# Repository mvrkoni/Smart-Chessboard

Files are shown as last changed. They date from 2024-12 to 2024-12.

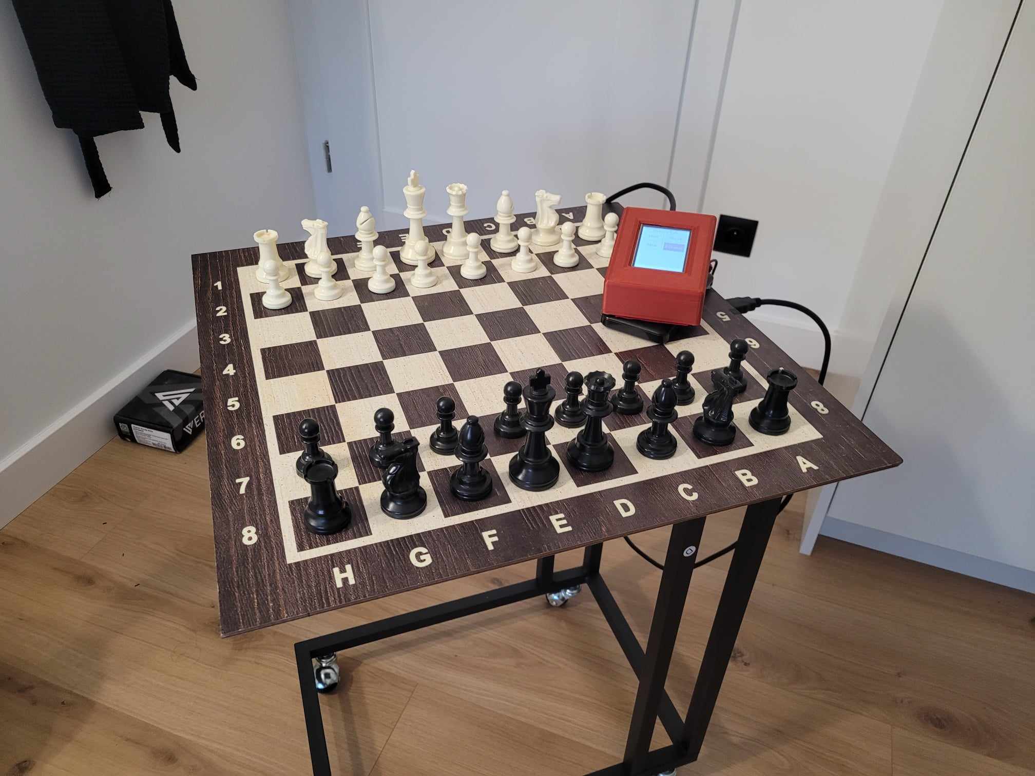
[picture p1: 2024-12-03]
Results_Images/465933476_549978397827990_7550162248625095663_n.jpg

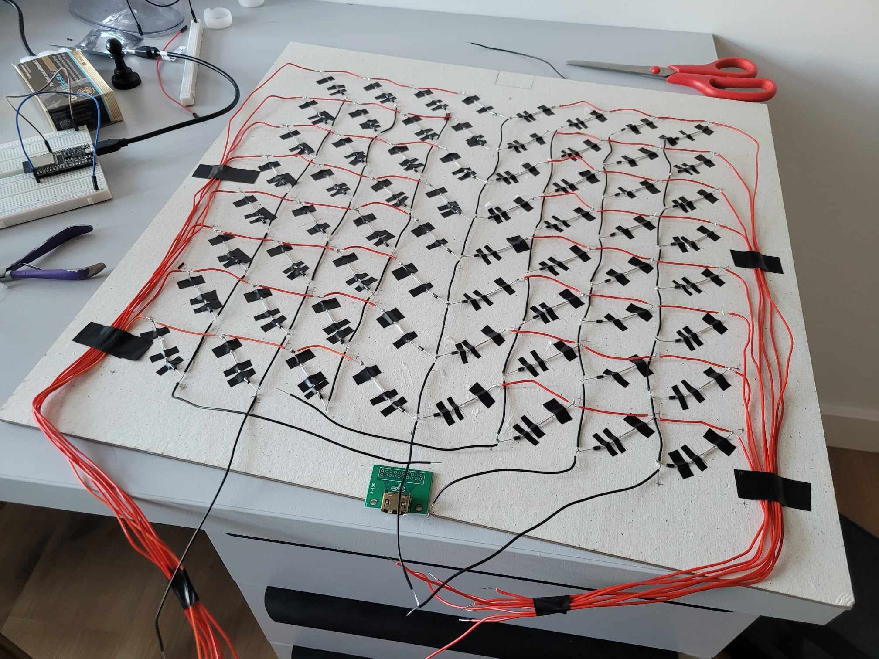
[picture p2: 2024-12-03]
Results_Images/464932877_1571432690404527_1509091106561519744_n.jpg

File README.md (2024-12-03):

                          SmartChessboard

This project is an ESP32-powered chessboard inspired by https://github.com/omercier01/Chessboard repository. It tracks chess pieces and sends game data to an external service like Lichess.

1. Documentation
   All details including:
   - Schematics: Electrical diagrams.
   - Code Explanation: Full code breakdown.
   - Setup Instructions: How to assemble and upload the code.

Everything is available in the documentation folder.

2. Result Images
   See the board in action in the Results_images folder.

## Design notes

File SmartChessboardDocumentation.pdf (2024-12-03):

Politechnika Lubelska
Wydział Elektrotechniki i Informatyki Inżynierskie Zastosowania Informatyki w Elektrotechnice

Imię i nazwisko autora:
Marek Rowiński
nr 93342

# Szachownica elektroniczna SmartBoard

Promotor:
dr inż. Jacek Majcher

Lublin, 2024

### Spis treści:

### 5. Projekt hardware’u

### 6. Projekt software’u

### 7. Analiza i wnioski

7.3. Możliwe usprawnienia i przyszłe kierunki rozwoju projektu.......17

### 1. Wprowadzenie

Elektroniczne szachownice to nowoczesne narzędzia, które rewolucjonizują tradycyjną grę w szachy poprzez integrację zaawansowanych technologii. Moim
celem jest | stworzenie | innowacyjnej | elektronicznej | szachownicy, | która
automatycznie rozpoznaje ruchy, umożliwia grę online i ułatwi analizę i█archiwizację partii.

Motywacją do realizacji projektu jest rosnące zainteresowanie grą w szachy oraz potrzeba dostarczenia narzędzia, które umożliwi graczom śledzenie rozgrywek w sposób nowoczesny i efektywny. Dzięki elektronicznym szachownicom, gra staje się bardziej dostępna, interaktywna i inspirująca.

### 2. Wymagania systemowe

System ma realizować szereg funkcji, które mają na celu ułatwienie i█udoskonalenie doświadczenia użytkownika. Główne funkcje obejmują:

- Gra online na platformie Lichess: Użytkownik będzie mógł grać partie szachów online poprzez integrację z platformą Lichess. System umożliwi logowanie się na konto Lichess, wyszukiwanie przeciwników oraz rozgrywanie partii w czasie rzeczywistym.
- Archiwizowanie partii na koncie Lichess: Podczas rozgrywki system będzie automatycznie zapisywał przebieg partii w formacie UCI na platformie Lichess, umożliwiając użytkownikowi późniejszą analizę i archiwizację rozgrywki.
- Interaktywny interfejs użytkownika: System będzie posiadał intuicyjny interfejs użytkownika, który umożliwi łatwe korzystanie z funkcji, takich jak rozpoczęcie nowej gry, wybór przeciwnika online oraz dostęp do zapisanych partii.

Dodatkowo, celem projektu jest stworzenie elektronicznej szachownicy łączącej funkcjonalność, estetykę i ergonomię, umożliwiającej grę w szachy w sposób wygodny i nowoczesny. Szachownica automatycznie rejestruje ruchy podczas gry, przesyła je do platformy Lichess, gdzie są zapisywane w formacie UCI, co eliminuje konieczność ręcznego wprowadzania posunięć. Dzięki temu użytkownik może analizować partie, korzystać z programów szachowych lub grać online – zarówno przeciwko komputerowi, jak i innym graczom na Lichess. Szachownica działa także jako urządzenie wejściowe, przenosząc ruchy wykonane na planszy bezpośrednio do aplikacji lub stron internetowych.

### 3. Sposób użytkowania

Elektroniczna szachownica jest wyposażona w wyświetlacz z interfejsem, który pokazuje czas trwania partii oraz oferuje podstawowe funkcje, takie jak gra online lub z komputerem (Stockfish 5). Aby rozpocząć grę, należy poprawnie ułożyć figury na szachownicy zgodnie z zasadami szachowymi. Aby sprawdzić czy położenie figur pokrywa się z czujnikami należy wejść do debug mode klikając boczny przycisk i wybrać odpowiednią opcję (Testowanie kontraktonów). Po ustawieniu figur, użytkownik może wybrać odpowiednią opcję na ekranie dotykowym, aby zagrać online lub z silnikiem.

Podczas gry, po wykonaniu ruchu przez gracza, należy delikatnie nacisnąć odpowiedni przycisk na ekranie dotykowym, aby wysłać ruch do serwerów Lichess. Wszystkie partie są zapisywane i dostępne na stronie lichess.org na koncie marekr93342. Ważne jest, aby figury były umieszczane równo i dokładnie na polach szachownicy, co zapewni prawidłowe działanie systemu detekcji ruchu.

W celu zapewnienia optymalnej wydajności i dokładności, należy dbać o█regularne czyszczenie powierzchni szachownicy i wyświetlacza.

### 4. Środki ostrożności zestawu elektronicznego

Do wykrywania elektronicznych figur szachowych na szachownicy używany jest rezonans elektromagnetyczny. Silny sygnał wygenerowany przez różnego rodzaju nadajniki w pobliżu urządzenia może spowodować samoistne i wadliwe wykrycie nieistniejących figur na danych polach szachownicy, tzw. zjawisko "figur duchów".

Jeśli problemy z wykrywaniem "figur duchów" występują podczas używania systemu, przyczyną może być umieszczenie szachownicy zbyt blisko ekranów plazmowych, monitorów LCD, głośników, zasilaczy i innych podobnych urządzeń. Metalowe powierzchnie lub przedmioty umieszczone obok, pod szachownicą lub pod stołem, na którym się ona znajduje, mogą zmniejszyć czułość systemu, co może spowodować błędy w wykrywaniu figur.

Nie należy umieszczać szachownicy na metalowej tablicy lub stole z█metalową konstrukcją pod blatem.

Sprzęt należy chronić przed skrajnymi warunkami atmosferycznymi, takimi jak deszcz, wysoka temperatura czy intensywne nasłonecznienie.

### 5. Projekt hardware’u

### 5.1. Schematy elektryczne:

Schematy | elektryczne | przedstawiają | szczegółowy | układ | połączeń
i█komponentów zastosowanych w elektronicznej szachownicy. Obejmują one rozmieszczenie czujników detekcji ruchu, układ zasilania, moduły komunikacyjne oraz interfejsy do przesyłania danych.

Schemat (Sch. 1.) składa się z diody Schottky'ego oraz kontraktonu. Kontraktony są używane do wykrywania obecności figur z wbudowanymi magnesami, natomiast dioda zapobiega powstawaniu fałszywych sygnałów w█układzie. Na schemacie (Sch. 2.) przedstawiono problem fałszywego odczytu sygnału w przypadku braku diod. Jeśli na trzech polach (A, C, D) są figury (zamknięte przełączniki), a na jednym polu (B) jej nie ma (otwarty przełącznik), sygnał mógłby niechcący przejść przez inne zamknięte pola i dać błędny odczyt.

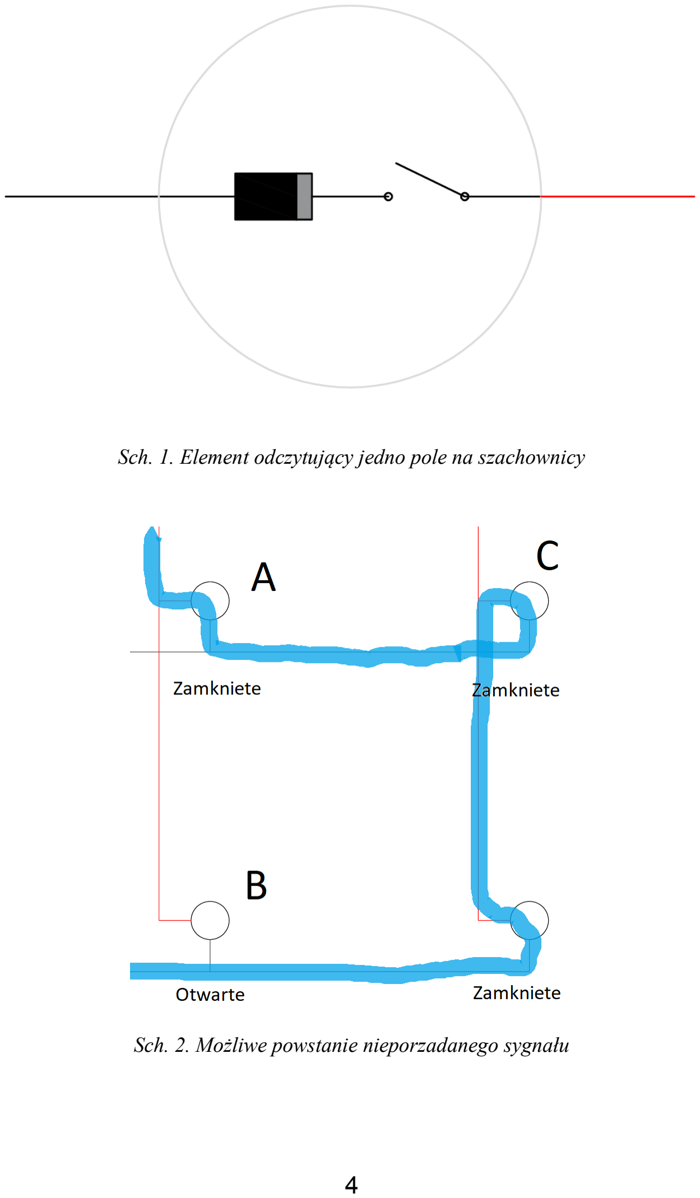
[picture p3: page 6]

Sch. 1. Element odczytujący jedno pole na szachownicy

Sch. 2. Możliwe powstanie nieporzadanego sygnału

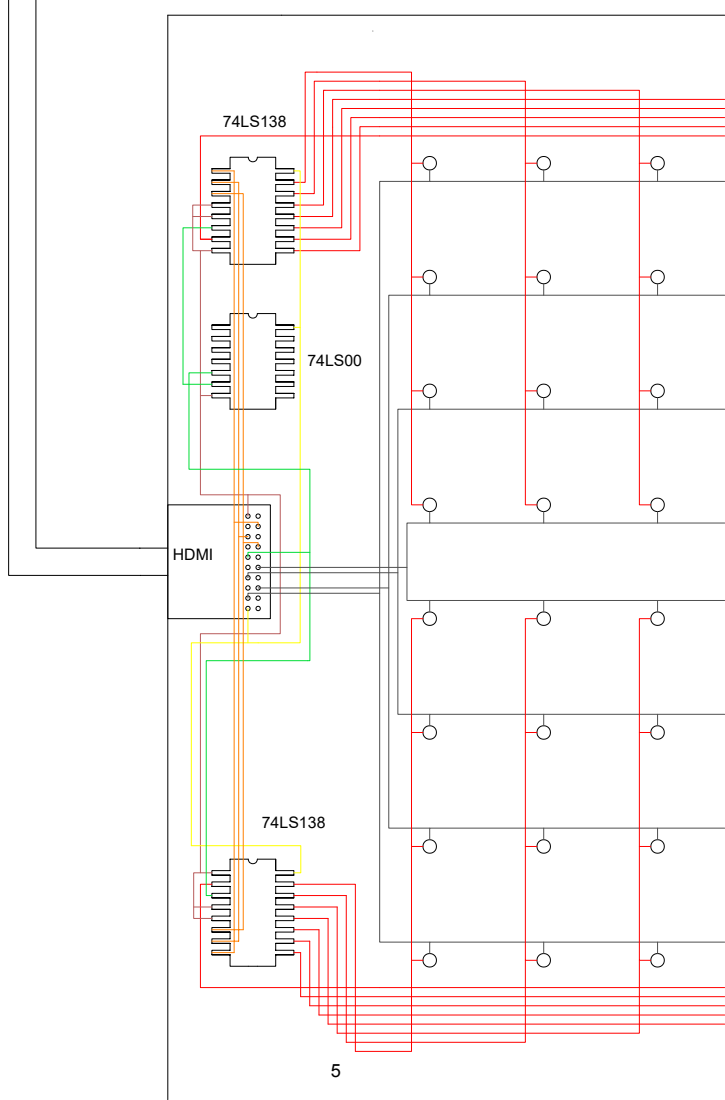
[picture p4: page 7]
HDMI

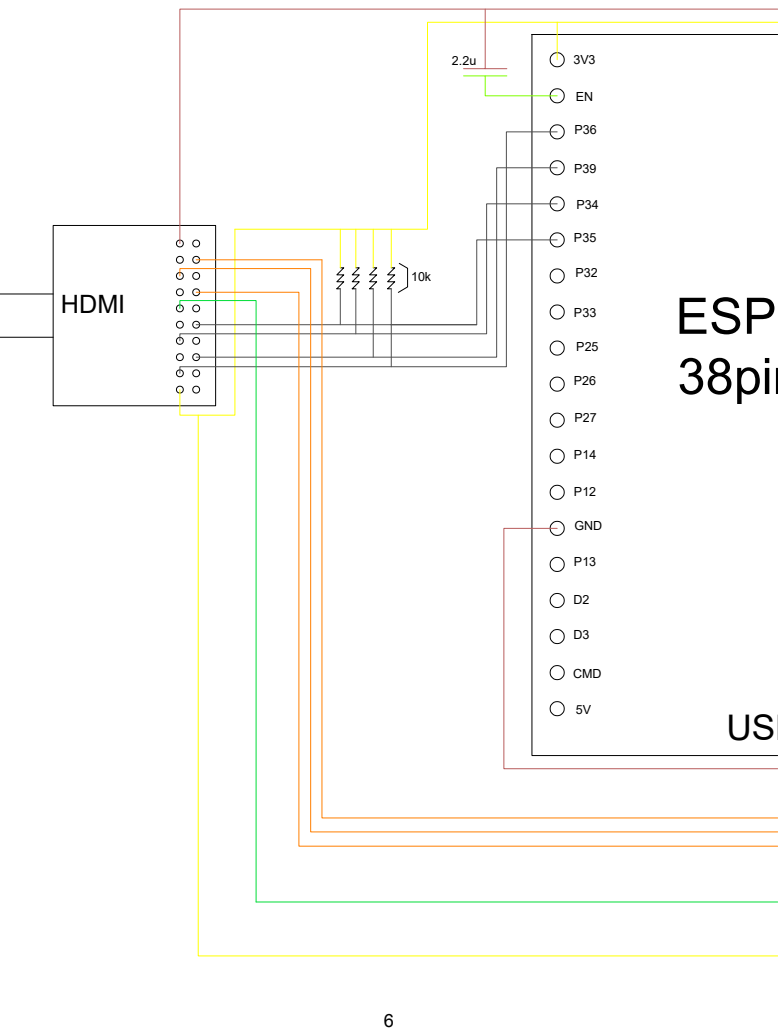
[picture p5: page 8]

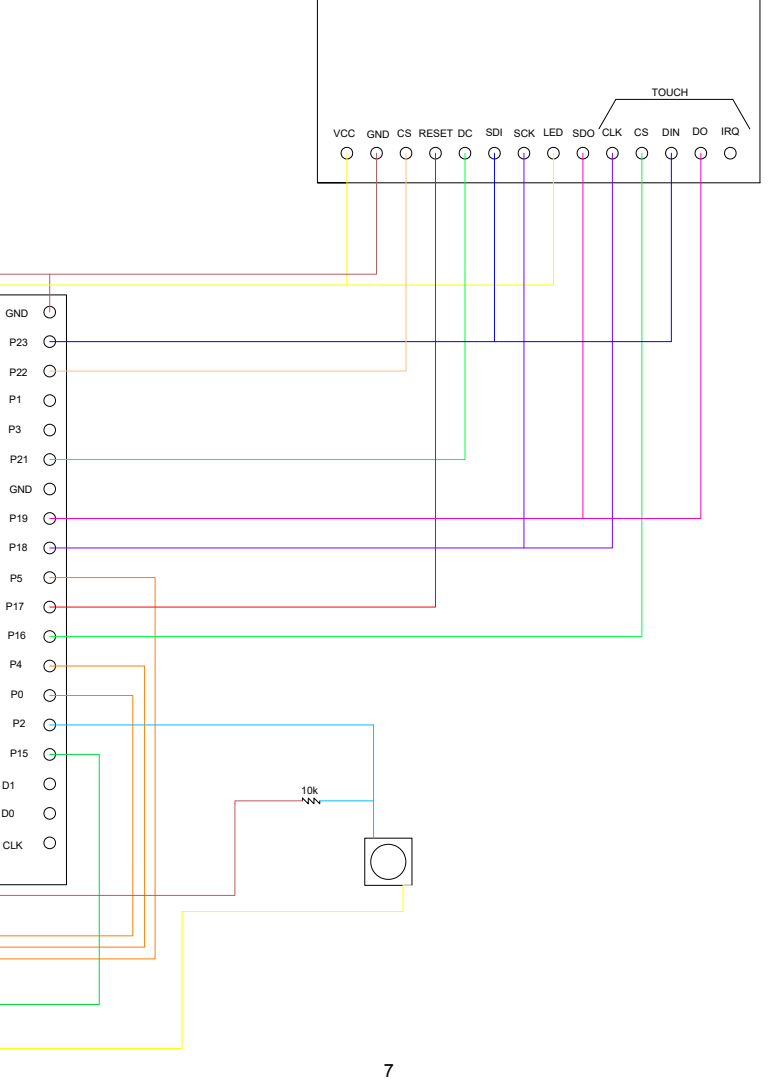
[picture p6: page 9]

VCC GND CS RESET DC SDI SCK LED SDO CLK CS DIN DO IRQ

W analizie schematów elektronicznych szachownicy można wyróżnić kluczowe elementy:

1. Rezystory 10k
Rezystory pełnią funkcję pull-up lub pull-down, stabilizując stan logiczny sygnału w przypadku jego braku, lub ograniczać prąd, chroniąc układ przed uszkodzeniem w razie zwarcia.
2. Kondensator 2,2 µF do masy (GND)
Kondensator eliminuje zakłócenia i stabilizuje napięcie, co zapobiega problemom podczas ładowania kodu.

### 5.2. Lista oraz opis poszczególnych komponentów:

− ESP32-DevKitC-32E V4 WiFi + BT 4.2

Platforma mikroprocesorowa wyposażona w moduł ESP-WROOM-32E. Oferuje wbudowane WiFi i Bluetooth 4.2, co umożliwia bezprzewodową komunikację z█siecią i innymi urządzeniami.

− Wyświetlacz dotykowy TFT LCD 2,8″ 240x320px

Wyświetlacz dotykowy o przekątnej 2,8 cala i rozdzielczości 240x320 pikseli. Służy do interaktywnej obsługi urządzenia, wyświetlania czasu gry, opcji menu oraz innych istotnych informacji. Technologia TFT zapewnia wyraźny obraz i█dobre kąty widzenia.

− Kabel HDMI - HDMI NEDIS 1.5 m

Standardowy kabel HDMI używany jako zbiór kabli do przesyłu i odbioru sygnałów z szachownicy.

− Demultiplexer 3 na 8 linii 74LS138

Układ scalony, który pozwala na wybór jednego z ośmiu wyjść na podstawie trzech sygnałów wejściowych. Umożliwia efektywne sterowanie wieloma liniami sygnałowymi przy użyciu mniejszej liczby przewodów sterujących.

− Bramka NAND 74LS00

Służy do negacji sygnału (zielony kabel). Sygnał zerojedynkowy dodany do zestawu sterującego (pomarańczowe kable) sprawia, że program rozróznia strony szachownicy

− Szachownica i figury szachowe

Fizyczna szachownica i figury służące jako sensor. Figury wyposażone są w magnesy neodymowe, które współpracują z kontaktronami umieszczonymi pod szachownicą, pozwalając na precyzyjne wykrywanie ruchów.

− Dioda Schottky’ego

Dioda półprzewodnikowa charakteryzująca się niskim napięciem przewodzenia i█dużą szybkością działania. W układzie zapobiega przepływowi sygnału w niepożądanym kierunku, eliminując błędy odczytu podczas wykrywania pozycji figur.

− Konstrukcja przewodowa z wyłącznikiem układu

Służy do zasilania oraz przesyłania danych między urządzeniami. Może być używany do podłączenia modułu ESP32 do komputera w celu programowania lub zasilania.

− Zestyk kontaktron prosty 14mm

Proste zestyki kontaktronowe, które zamykają obwód w obecności pola magnetycznego. Umieszczone pod polami szachownicy, umożliwiają wykrywanie pozycji figur szachowych wyposażonych w magnesy.

− Rezystor justPi THT CF węglowy 1/4W 10kΩ

Rezystory węglowe, używane do ograniczania prądu w obwodach. Chronią inne komponenty przed uszkodzeniem przez nadmierny prąd oraz służą do ustawiania odpowiednich poziomów sygnałów.

− Magnes neodymowy okrągły 6x3mm

Magnesy neodymowe, które są umieszczane w figurach szachowych. Oddziałują na zestyki kontaktronowe pod szachownicą, umożliwiając precyzyjne wykrywanie pozycji figur.

− Powerbank Tracer 10000mAh

Powerbank służący jako źródło zasilania.

Dodatkowo:

− Przewody połączeniowe
− Obudowa wydrukowana w drukarce 3D
− Porty HDMI
− Adapter USB Typ C - Micro USB LANBERG AD-UC-UM-01 − Tact switch 6x6

### 5.3. Kosztorys

Nazwa: | Cena (w zł): | Ilość:
ESP32 - 38pin | 59,99 | 1x
Wyświetlacz | 40,00 | 1x
74LS138n | 1,50 | 3x
74LS00n | 6,00 | 1x
Zestaw figur | 33,00 | 1x
Szachownica | 59,00 | 1x
Diody | 0,15 | 64x
Magnesy | 0,55 | 34x
Kontraktony | 0,85 | 64x
Wyłącznik układu | 16,24 | 1x
Zestaw kabli | 59,90 | 1x
Adapter do ESP32 | 16,00 | 1x
Adapter USB - B | 6,99 | 1x
Obudowa | 30,00 | 1x
Śrubki i nakładki | 3,00 | 1x
Powerbank | 50,00 | 1x
Płytka stykowa 170o. | 3,50 | 2x
Porty HDMI | 5,55 | 2x
SUMA: | 501,12

### 6. Projekt software'u

W systemie działa kilka kluczowych mechanizmów, które pozwalają na rozgrywanie partii, śledzenie ruchów, obsługę różnych stanów gry oraz interakcję z użytkownikiem poprzez menu. Poniżej znajduje się bardziej szczegółowy opis poszczególnych elementów i ich logiki:

### 6.1. Odczytywanie figur z szachownicy

Szachownica jest wyposażona w kontraktony, które umożliwiają wykrywanie obecności figur na poszczególnych polach. Odczytywanie figur odbywa się poprzez skanowanie stanu szachownicy i porównywanie go z█oczekiwanym stanem (Rys. 1-3.):

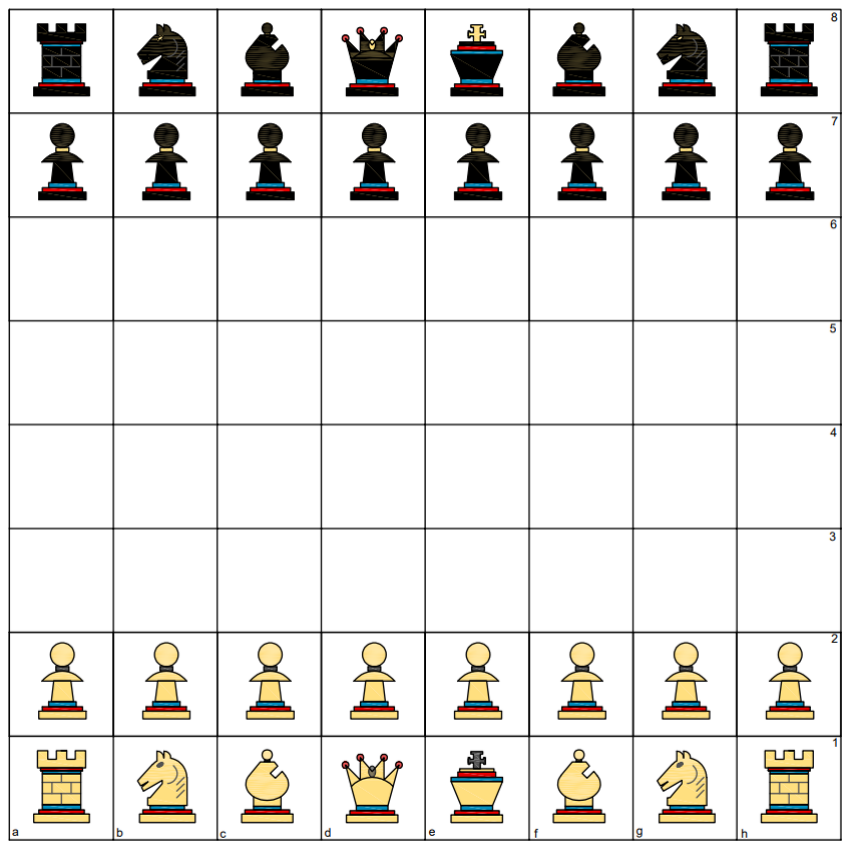
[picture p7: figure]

Sch. 5. Pierwotne ustawienie figur

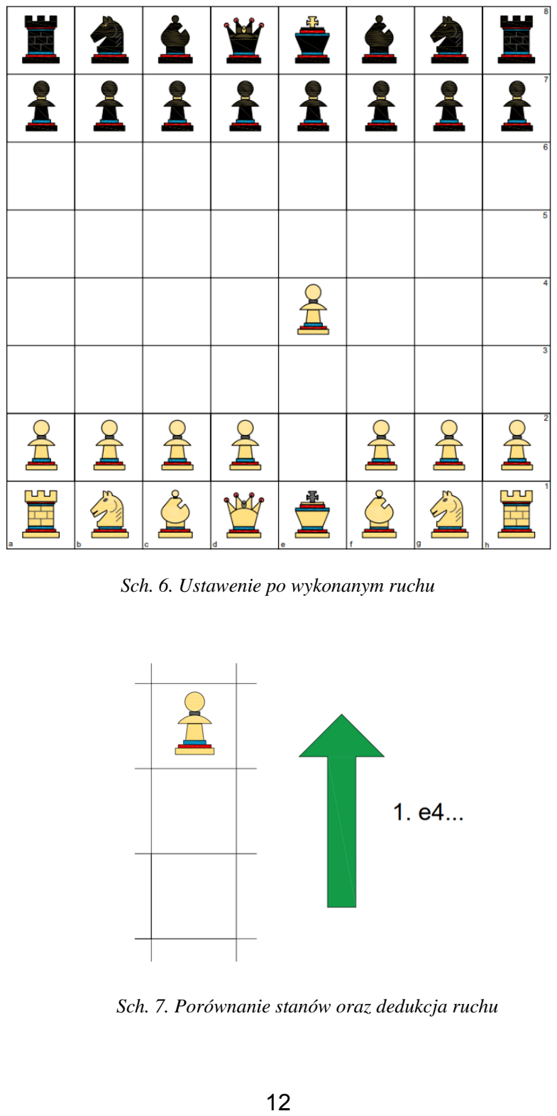
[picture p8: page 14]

Sch. 6. Ustawenie po wykonanym ruchu

Sch. 7. Porównanie stanów oraz dedukcja ruchu

Kluczowe funkcje związane z tym procesem to:

- checkUpdatedSquaresForMoves(): Ta funkcja sprawdza, które pola na szachownicy zostały zmienione od ostatniego odczytu. Na tej podstawie określa, jakie ruchy zostały wykonane. W zależności od liczby zmienionych pól rozpoznaje różne rodzaje ruchów (prosty ruch, bicie, promocja, en passant, roszada).
- getChangedSquares(): Funkcja ta zwraca listę pól, które zostały zmienione od ostatniego skanu. Jest to kluczowa funkcja do śledzenia zmian na szachownicy.
- isPlayerPiece() i isOpponentPiece(): Te funkcje sprawdzają, czy dana figura na określonym polu należy do gracza, czy do przeciwnika.

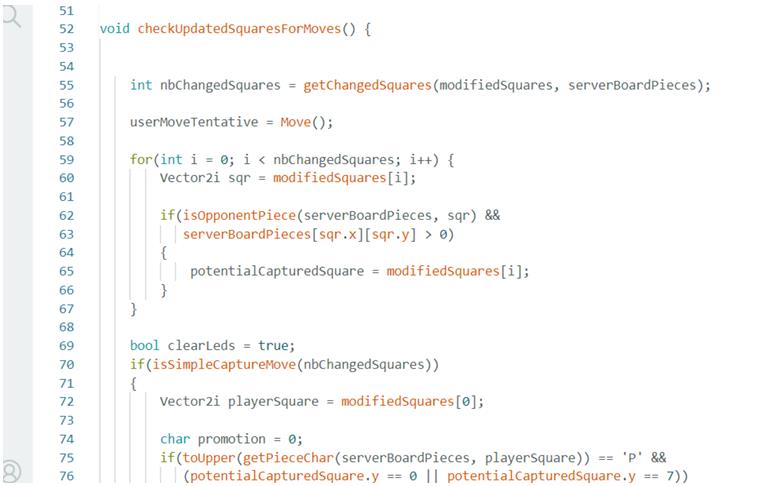
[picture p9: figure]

Zdj. 1. Element kodu

### 6.2. Tworzenie ruchów w formacie UCI

UCI (Universal Chess Interface) to standardowy protokół komunikacyjny dla silników szachowych. System generuje ruchy w formacie UCI na podstawie wykrytych ruchów. Oto kluczowe elementy tego procesu:

- squaresToMove(): Ta funkcja tworzy obiekt ruchu (ang. Move) na podstawie pozycji początkowej i końcowej figury oraz ewentualnej promocji. Obiekt Move zawiera informacje potrzebne do zapisu ruchu w formacie UCI.
- userMoveTentative.toString(): Konwertuje obiekt ruchu na jego reprezentację tekstową w formacie UCI, która może być wyświetlona użytkownikowi lub wysłana do serwera.

### 6.3. Logika stanu gry

Stan gry jest zarządzany za pomocą zmiennej gameState, która może przyjmować różne wartości określające bieżący etap gry. Kluczowe etapy to:

- GameState::Connecting: Łączenie z serwerem lub przeciwnikiem.
- GameState::NoGame: Brak aktywnej gry.
- GameState::GameFound: Znalezienie przeciwnika i rozpoczęcie gry.
- | GameState::WaitingToReceiveOpponentMove: | Oczekiwanie | na | ruch
przeciwnika.
- GameState::UserMakingUserMove: Użytkownik wykonuje swój ruch.
- GameState::WaitingToReceiveUserMoveConfirmation: Oczekiwanie na potwierdzenie ruchu użytkownika przez serwer.

Każdy stan jest odpowiednio obsługiwany przez wyświetlanie odpowiednich menu i komunikatów na ekranie, np. informowanie użytkownika o ruchu przeciwnika czy konieczności wykonania ruchu.

### 6.4. Obsługa interakcji z użytkownikiem

System obsługuje interakcje użytkownika poprzez menu wyświetlane na ekranie. Menu zmieniają się dynamicznie w zależności od stanu gry. Funkcja mainLoop_Game() jest główną pętlą sterującą grą i obsługującą wszystkie stany oraz interakcje użytkownika.

### 6.5. Zarządzanie czasem i zegarem

System śledzi czas pozostały dla obu graczy i odpowiednio aktualizuje wyświetlanie zegara. Zmienne takie jak playerTimeLeft i opponentTimeLeft są aktualizowane na bieżąco w zależności od aktywnego gracza.

### 6.6. Potencjalne ruchy i bicie

Funkcje takie jak checkPotentialCaptureSquareWithSentMove() oraz checkUpdatedSquaresForMoves() sprawdzają, czy wykonane ruchy są legalne i█czy doszło do bicia figury przeciwnika. Na tej podstawie system może aktualizować stan gry i informować użytkownika o koniecznych działaniach, np. resetowaniu nielegalnego ruchu.

Cała logika sieciowa znajduje się w pliku NetworkLoop.ino.

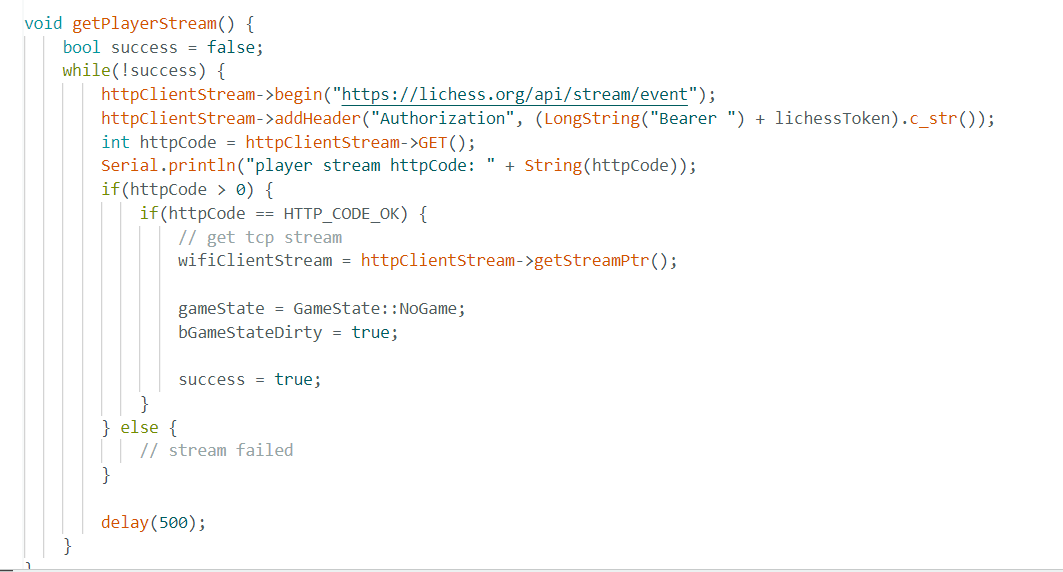
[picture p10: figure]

Zdj. 2. Główna pętla odpowiadająca na wyszukiwanie gry w pliku Network.ino

### 7. Analiza i wnioski:

### 7.1. Ocena rezultatów

Projekt z sukcesem połączył sprzęt i oprogramowanie do gry w szachy, umożliwiając śledzenie ruchów na fizycznej szachownicy oraz ich wyświetlanie w█aplikacji. Interfejs użytkownika jest intuicyjny i wygodny. Niestety, tryb dla dwóch graczy (jeden z głównych celów) nie został zaimplementowany.

### 7.2. Analiza problemów i rozwiązań

Projekt napotkał trudności z kalibracją czujników oraz interpretacją ruchów, ale te problemy zostały rozwiązane dzięki testom i iteracyjnemu debugowaniu. Użycie ESP32 zewnętrznej anteny mogłoby poprawić stabilność sygnału Wi-Fi, co wpłynęłoby na niezawodność połączenia.

### 7.3. Możliwe usprawnienia i przyszłe kierunki rozwoju

Projekt może być rozwinięty poprzez dodanie opcji konfiguracji silnika szachowego, umożliwiającej dostosowanie go do potrzeb gracza. Dodatkowo, usprawnienie wyświetlania ruchów w notacji PGN, rozbudowa menu silnika szachowego oraz dodanie funkcji większej personalizacji menu (np. ustawienia partii, analiza statystyk) poprawiłoby doświadczenia użytkownika. Integracja z█platformami społecznościowymi do udostępniania partii i prowadzenia rankingów to także możliwy kierunek rozwoju.

### 8. Bibliografia:

Filmy:

- https://youtu.be/ZDDEnBZZvmo?list=LL - Foldable Electronic Chess Board
- an overview
- https://youtu.be/Qv0fvm5B0EM?list=LL - Code CHESS in JavaScript
- https://youtu.be/D84sVPR6g7o - Smart Chess board Arduino project

Artykuły:

- https://projecthub.arduino.cc/maguerero/automated-chess-board-67db6f -Automated Chess Board
- https://electronics.stackexchange.com/questions/551581/detecting-chess-pieces-on the-board - Detecting chess pieces on the board
- https://kcir.pwr.edu.pl/~witold/ip/2019_reports/BoczarJedrzej_IP_final_repo rt.pdf - Chess pieces detecting – Politechnika Wrocławska

Materiały:

- https://github.com/omercier01/Chessboard/tree/main

Elementy CAD:

- https://www.bibliocad.com/en/library/chess-pieces_59883/ | - | Figury
szachowe

Poza materiałami korzystałem z konsultacji mailowych z twórcą oprogramowania. Oprogramowanie zostało przeze mnie przerobione na własny użytek. Oprogramowanie zawiera MIT Licence, co umożliwia dokonanie edycji oraz skorzystania z tego programu zgodnie z prawem. Dodatkowo korzystałem z█narzędzia ChatGPT.

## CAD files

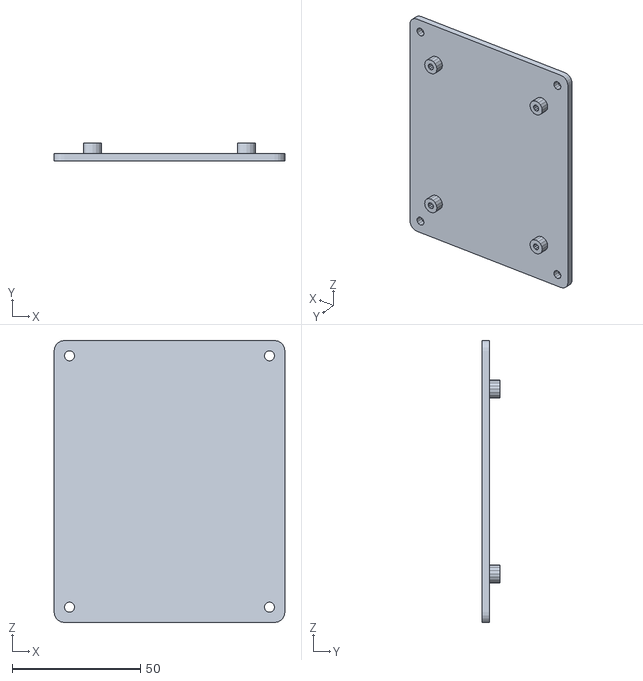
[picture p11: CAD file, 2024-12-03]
Inventor/Czesc1.stl
90.0 x 7.00 x 110.0

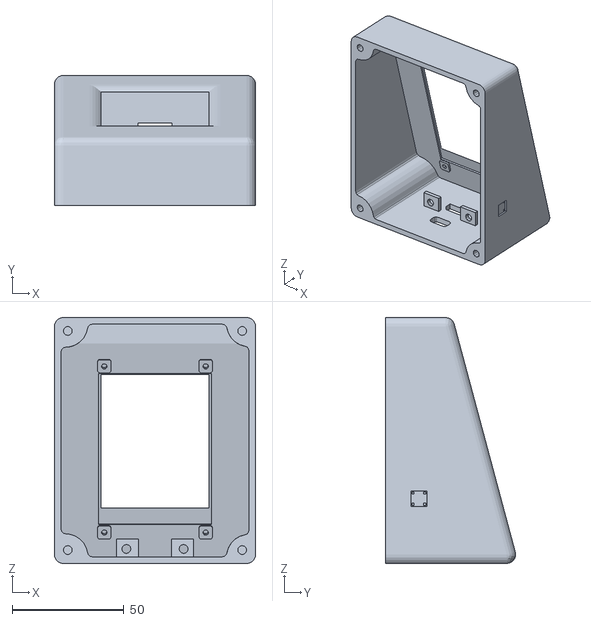
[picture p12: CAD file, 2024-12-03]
Inventor/Czesc2.stl
90.0 x 58.2 x 110.0

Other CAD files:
Inventor/Część1.ipt
Inventor/Część2.ipt

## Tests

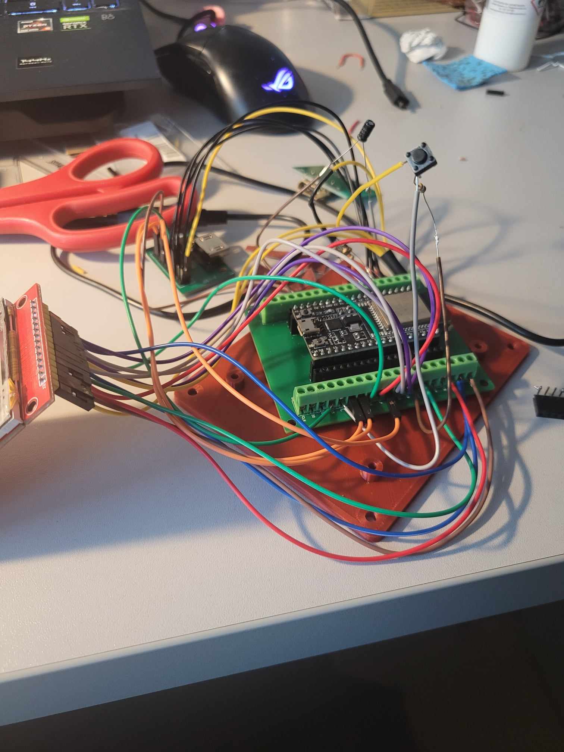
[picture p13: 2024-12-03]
Results_Images/462586700_546898468313112_7553431870098252159_n.jpg

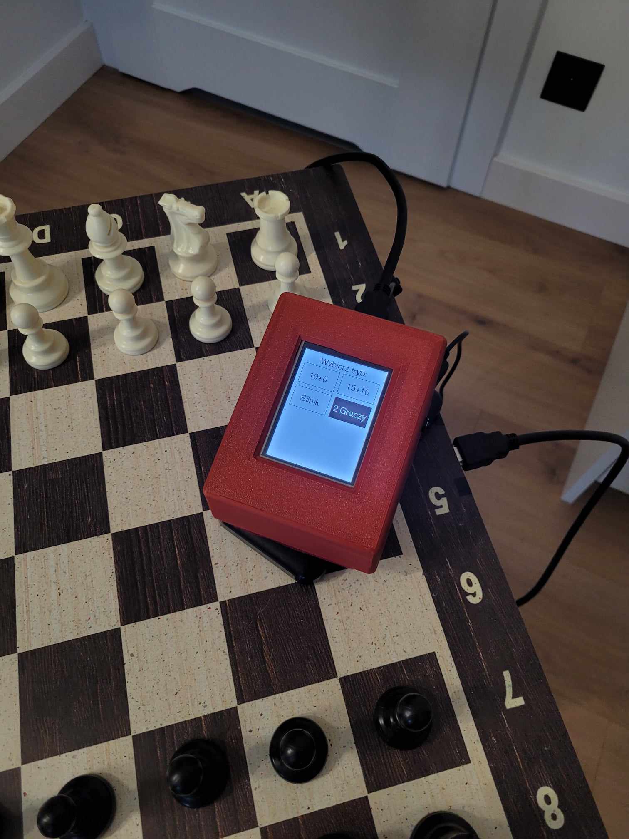
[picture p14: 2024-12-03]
Results_Images/465755223_1135674761450074_6425332109045614567_n.jpg

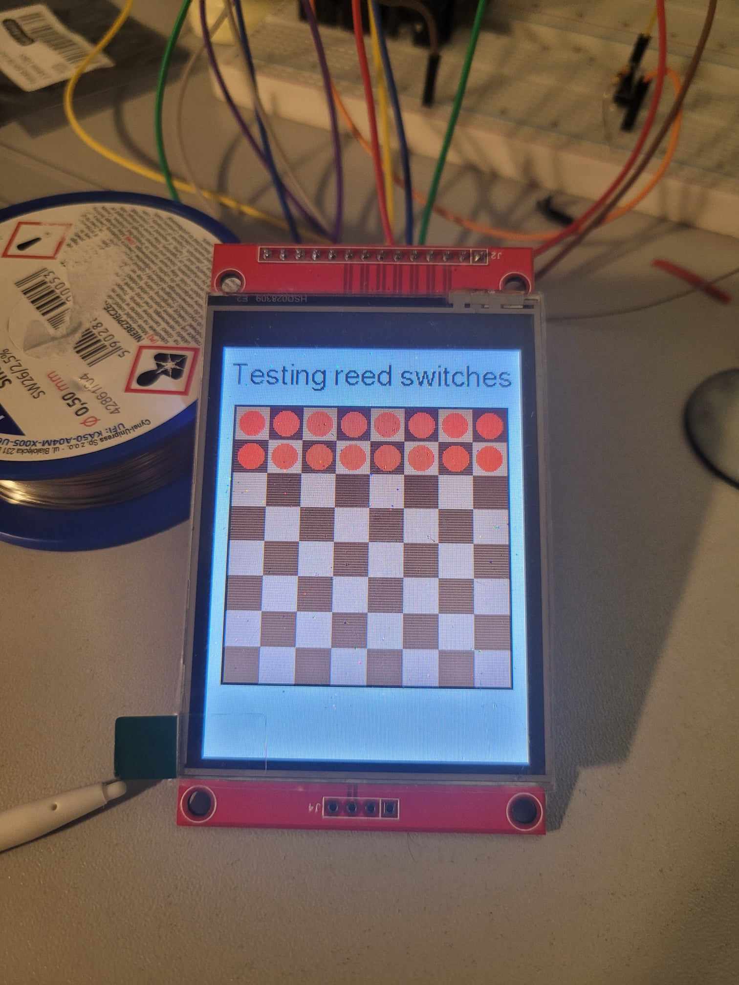
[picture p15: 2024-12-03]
Results_Images/462559020_935698035289928_941344268324166587_n.jpg

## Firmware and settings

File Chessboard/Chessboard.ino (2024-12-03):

#include "Chessboard.h"
#include "NetworkLoop.h"
#include "MainLoop.h"
#include "MainLoop_LedTest.h"
#include "LedLoop.h"
#include "Menus.h"
#include "PersistentParam.h"

#if defined(BOARD_DEF_RP2040)
    TFT_eSPI tft;
    struct repeating_timer timer;
#endif

void setup() {
    
    Serial.begin(115200);

    Serial.println("starting...");
    
#if defined(BOARD_DEF_ESP32)
    pinMode(PIN_MAINMODE_BUTTON, INPUT);
#elif defined(BOARD_DEF_RP2040)
    pinMode(PIN_MAINMODE_BUTTON, INPUT_PULLDOWN);
#endif

    pinMode(PIN_SWITCH_IN_0, INPUT);
    pinMode(PIN_SWITCH_IN_1, INPUT);
    pinMode(PIN_SWITCH_IN_2, INPUT);
    pinMode(PIN_SWITCH_IN_3, INPUT);
    
    pinMode(PIN_SWITCH_QUERY_0, OUTPUT);
    pinMode(PIN_SWITCH_QUERY_1, OUTPUT);
    pinMode(PIN_SWITCH_QUERY_2, OUTPUT);
    pinMode(PIN_SWITCH_QUERY_3, OUTPUT);
    
    pinMode(PIN_LED_POS_0, OUTPUT);
    pinMode(PIN_LED_POS_1, OUTPUT);
    pinMode(PIN_LED_POS_2, OUTPUT);
    pinMode(PIN_LED_POS_3, OUTPUT);
    
    pinMode(PIN_LED_NEG_0, OUTPUT);
    pinMode(PIN_LED_NEG_1, OUTPUT);
    pinMode(PIN_LED_NEG_2, OUTPUT);
    pinMode(PIN_LED_NEG_3, OUTPUT);


    PersistentParamBegin();
    touchCalibrationData.x0 = PersistentParamLoadFloat(PersistentParamType::TouchX0);
    touchCalibrationData.dxdx = PersistentParamLoadFloat(PersistentParamType::TouchDxDx);
    touchCalibrationData.dxdy = PersistentParamLoadFloat(PersistentParamType::TouchDxDy);
    touchCalibrationData.y0 = PersistentParamLoadFloat(PersistentParamType::TouchY0);
    touchCalibrationData.dydx = PersistentParamLoadFloat(PersistentParamType::TouchDyDx);
    touchCalibrationData.dydy = PersistentParamLoadFloat(PersistentParamType::TouchDyDy);
    wifiName = PersistentParamLoadString(PersistentParamType::WifiName).c_str();
    wifiPassword = PersistentParamLoadString(PersistentParamType::WifiPassword).c_str();
    lichessToken = PersistentParamLoadString(PersistentParamType::LichessToken).c_str();
    lichessBoardAccountUsername = PersistentParamLoadString(PersistentParamType::LichessBoardAccountUsername).c_str();
    lichessBoardAccountToken = PersistentParamLoadString(PersistentParamType::LichessBoardAccountToken).c_str();
    twoPlayersTimePerSide = PersistentParamLoadInt(PersistentParamType::TwoPlayersTimePerSide);
    twoPlayersIncrement = PersistentParamLoadInt(PersistentParamType::TwoPlayersIncrement);
    PersistentParamEnd();

    twoPlayersTimePerSide = clamp(twoPlayersTimePerSide,
                                  twoPlayersTimePerSideMin,
                                  twoPlayersTimePerSideMax);

    twoPlayersIncrement = clamp(twoPlayersIncrement,
                                twoPlayersIncrementMin,
                                twoPlayersIncrementMax);


#if defined(BOARD_DEF_ESP32)
    bus = Arduino_ESP32SPI(PIN_TFT_DC, PIN_TFT_CS, PIN_TFT_SCK, PIN_TFT_MOSI, PIN_TFT_MISO);
    pDisplay = new Arduino_ILI9341(&bus, PIN_TFT_RESET);

    pDisplay->begin(displaySpeed);
    pDisplay->setRotation(2);

    pTouch = new XPT2046_Touchscreen(PIN_TFT_TOUCH_CS);
    pTouch->begin();
#elif defined(BOARD_DEF_RP2040)
    tft.init();
    tft.setRotation(2);
#endif

LightLed(-1,-1);
    


#if defined(BOARD_DEF_ESP32)
    // In the main game mode, the network thread does all the work, and the main thread only does display and input/output. In the debug modes, the main thread does all the work.
    xTaskCreatePinnedToCore( networkLoop, "networkLoop", networkTaskStackSize, NULL, 1, &networkTask, 0);

    // Prioritize LEDs loop on main core. Very visible when the LEDs are not smooth, so
    // we want to keep that thread running smoothly if possible.
    xTaskCreatePinnedToCore( ledLoop, "ledLoop", ledTaskStackSize, NULL, 2, &ledTask, BaseType_t(1));
#elif defined(BOARD_DEF_RP2040)
    multicore_launch_core1(networkLoop);
#endif

    for(int i = 0; i < 8; i++) {
        for(int j = 0; j < 8; j++) {
            clientBoardBool[i][j] = 0;
            clientBoardBoolTempWrite[i][j] = 0;
            serverBoardPieces[i][j] = 0;
        }
    }

    // document to receive json info from lichess
    jsonDocStream = new DynamicJsonDocument(jsonDocumentAllocSize);

    // not sure how much these are necessary
    httpClientStream->setReuse(false);
    httpClientStream->useHTTP10(true);
    httpClientApi->useHTTP10(true);

    knownServerMoves = new Move[MAX_NB_MOVES+2];

    timeLastDummyMovePost = millis();
    timeLastTimerDrawUpdate = millis();
    timeLastTimerReceived = millis();

    Serial.println("initialized.");
    
#if defined(BOARD_DEF_RP2040)
    add_repeating_timer_us(1000, ledLoop, NULL, &timer);
#endif
}



// main loop runs on core 1 by default
void loop() {
    mainLoop();
}
